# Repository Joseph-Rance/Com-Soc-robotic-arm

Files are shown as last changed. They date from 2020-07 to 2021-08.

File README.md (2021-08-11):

**WE'RE DONE! Thanks to everyone who took part! ([VIDEO](https://github.com/Joseph-Rance/Com-Soc-robotic-arm/blob/master/final%20video.mp4))**

# Com-Soc-robotic-arm
Repo for the code for our robotic arm project

Main Com Soc Repo: https://github.com/CRGS-Computing-Society/Com-Soc-main

## Object detection

The program first takes in an image like the one below as well as an image of the same scene but without objects on it.

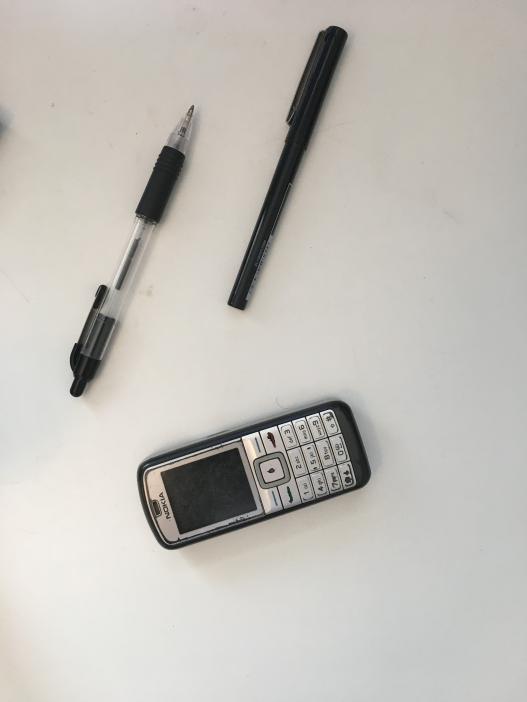
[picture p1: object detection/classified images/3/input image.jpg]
input image


It then takes the difference between the two images to get a map of where the added objects may be, cleans the map up, and then finds the centre of the objects using DBSCAN. Below shows the predicted centres of objects in the image, marked by red dots.

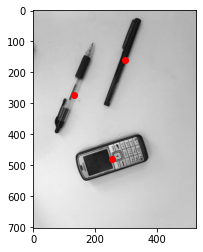
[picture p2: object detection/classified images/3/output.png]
output image


*Note: The only inputs are the background image and the image with objects in. No other information is used, including how many objects are in the image*

The algorithm also identifies the best angle to rotate the hand to get the best grip on the object

## Cad model render

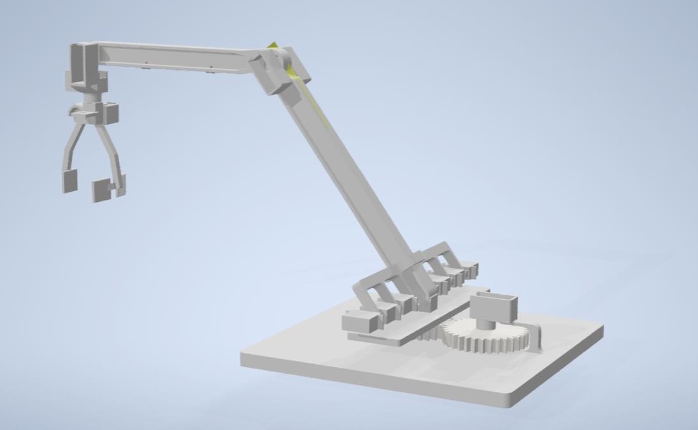
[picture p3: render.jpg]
arm render


# TODO

- [X] finish TODOs in [combined/main.py](https://github.com/Joseph-Rance/Com-Soc-robotic-arm/blob/master/combined/main.py)
- [x] fix issues with servo power supply (add new cables?)
- [X] test code with each set of servos ~~+ update code to reduce jitter and allow for gearing~~
- [X] add servos in at the correct orientation
- [X] test arm as whole + fix any problems (inc. fixing horizontal rotate servo, up/down gripper, and checking main.py is up to date with move_arm.py)

# servo offsets

```
0 -> 0 to 25
1 -> 90 (inv)
2 -> 0
3 -> 0
4 -> 0 (inv)
5 -> -3
6 -> -3
7 -> 0
8 -> 5 (inv)
9 -> 12 (inv)
10 -> 5 (inv)
11 -> 22 (inv, gear)
```

**Calibration dots are (-10, 35), (10, 30) cm**

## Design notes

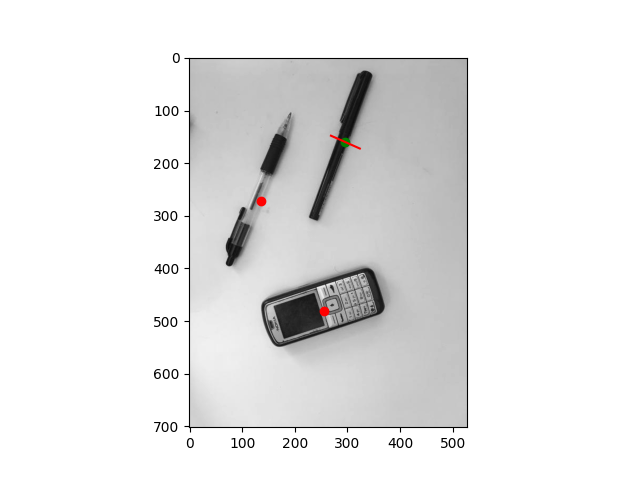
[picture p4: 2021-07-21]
object detection.png

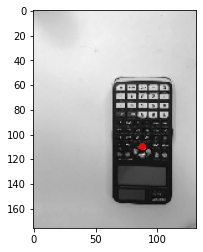
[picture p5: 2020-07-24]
object detection/classified images/2/output.png

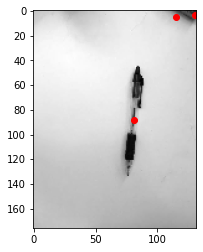
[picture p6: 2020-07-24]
object detection/classified images/1/output.png

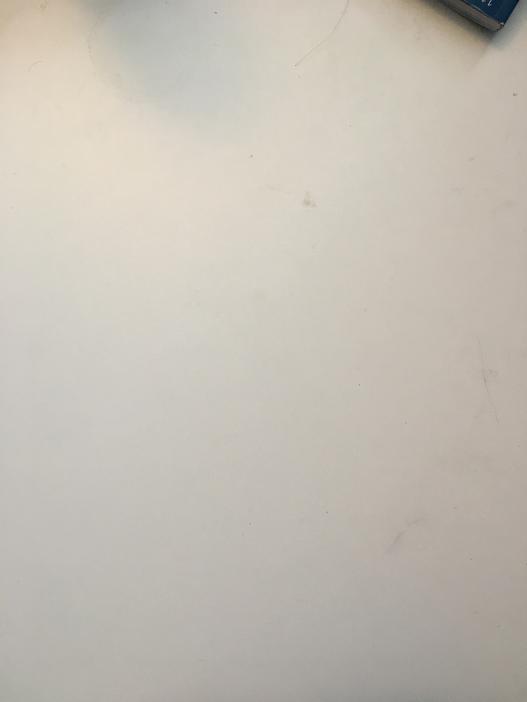
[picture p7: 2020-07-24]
object detection/classified images/1/input background.jpg

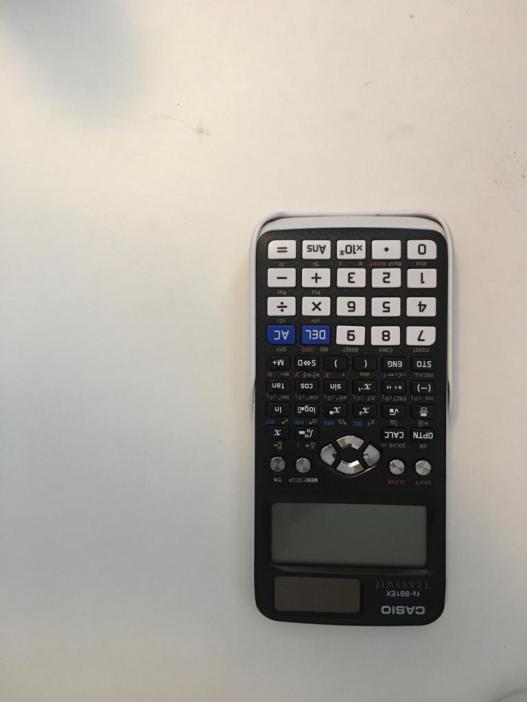
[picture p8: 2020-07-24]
object detection/classified images/2/input image.jpg

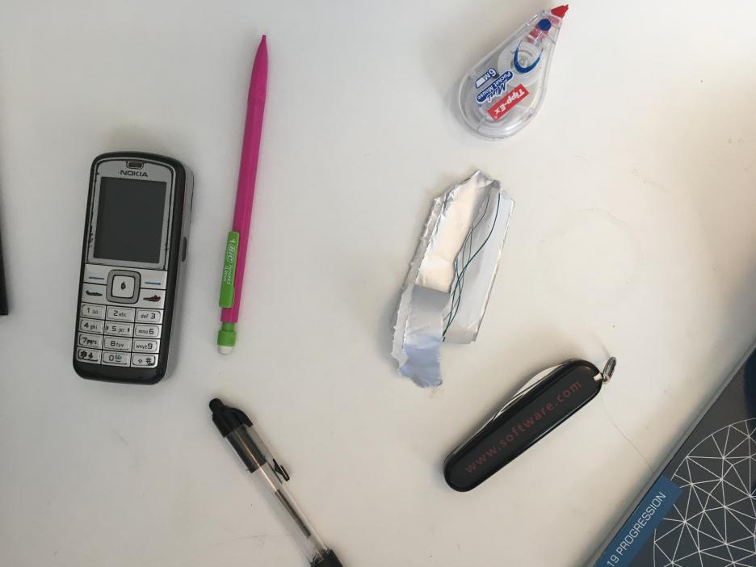
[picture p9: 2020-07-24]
object detection/classified images/4/input image.jpg

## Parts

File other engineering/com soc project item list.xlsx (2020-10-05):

Item | Link | Price (£)
Raspberry Pi | https://thepihut.com/products/raspberry-pi-4-model-b?variant=20064052740158 | 54
Pi camera display cable extension | https://www.adafruit.com/product/2143 | 3.95
GPIO extension cables | https://www.amazon.co.uk/AZDelivery-MB-102-Breadboard-Kit/dp/B07KYHBVR7 | 5.49
Cable ties | https://www.amazon.co.uk/100-Pack-Black-Cable-Ties/dp/B07BGTR4G4 | 5.69
Power supply (rpi) | https://thepihut.com/products/official-raspberry-pi-universal-power-supply?src=raspberrypi | 9
3D printer filament (2 for safety) | https://www.amazon.co.uk/ANYCUBIC-Printer-Filament-Printing-Printers/dp/B07DMF9ZRL | 61.96
Servos (6 * 2) | https://www.amazon.co.uk/Diymore-Digital-Helicopter-Airplane-controls/dp/B07DQJ1JXY | 53.8
Camera | https://thepihut.com/products/raspberry-pi-camera-module?src=raspberrypi | 24
Rubber pads for gripper | https://www.amazon.co.uk/Adhesive-Bumpers-Cylindrical-Hemispherical-Trapezoid/dp/B01M7OAWNU | 6.99
usb-c adapter | https://thepihut.com/products/usb-b-to-usb-c-adapter | 1
servo controller | https://www.adafruit.com/product/815 | 14.95
servo controller power supply | https://www.amazon.co.uk/Adapter-aifulo-Universal-Adapters-Speakers/dp/B08CZ9VTSH | 8.99
 |  | 249.82 | (max is £250)

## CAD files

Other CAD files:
cad/Spur Gear16.ipt
cad/Spur Gear26.ipt
cad/Spur Gears6.iam
cad/arm base holder 1.ipt
cad/arm.iam
cad/bullet bill 1.ipt
cad/cross section 2.ipt
cad/moving gripper 2.ipt
cad/servo holder 2.ipt
cad/servo placeholder.ipt
cad/stationary gripper 7.ipt
cad/wood part 1.ipt
cad/wood part 2.ipt
cad/wrist 3.ipt
cad/x arm 2.ipt
cad/y arm 2.ipt
cad/y arm connection.ipt

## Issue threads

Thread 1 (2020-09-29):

TODO

Joseph-Rance, 2020-09-29:
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

Joseph-Rance, 2020-10-16:
UPDATE 16/10/2020:

I got together a list of parts for the servo power supply, and the components have been sent off. We will be meeting at 6:30 Saturday to discuss the CAD modelling

BlueScorch2, 2020-10-20:
:]

Joseph-Rance, 2020-10-20:
From the call:
1. ~~What type of Claw to use~~ one finger will bee fixed, the other attached to servo. the stationary finger will be split in two (not too wide though)
2. ~~Best way to attach servos to arm- ie. 3d printed mould, glue, etc~~ Glue in bottom of cup
3. ~~Best way to attach servo axles to next part~~ see pinned diagram; see pinned link for servo connection
4. ~~What type of base (eg should we just stick it to a big piece of mdf)~~ make sheet on bottom go paast servos to put weight on (e.g. book)
5. ~~Best cross section shape~~ needs cad stress testing
6. ~~how to connect the arm to the servo axles~~ see pinned  diagram (3)
7. ~~how to connect the joints~~ see pinned  diagram (3)
8. ~~how to connect that arm together in general~~ see second pinned diagram
10. ~~modularity?~~ use modular fingers (make them easily removable
11. add camera mount to gripper
12. see last pinned diagram for servo locations

Joseph-Rance, 2020-10-20:
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
[link](https://www.amazon.co.uk/Diymore-Digital-Helicopter-Airplane-controls/dp/B07DQFXDC9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)
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

Joseph-Rance, 2020-10-23:
Because we need to make a decision on this and I keep forgetting to bring it up in meetings, I'm just going to make it now: x = 0.4m; y = 0.35m.

Joseph-Rance, 2020-10-23:
**MESSAGE FROM COM SOC DISCORD**
@BlueScorch2#0323 @Greedypig212#6943 @Rebi#9845 So its going to be us 4 and Hemanth working on the arm.

Mr. McCain mentionned that we have two different 3D printers when we met him at lunch. The filament we are getting is 1.75mm so we'll be using the *flash forge finder* (in case you need any specifications for part size etc.)

I think it will be best if we give each person a specific part to work on. I want to decide what everyone is going to be doing ASAP so if anyone is feeling inspired they can begin already, however we have admissions tests coming up so we'll only properly begin modelling on the week beginning the 9th. I think we should aim to have models complete two weeks after that.

Of course, we will almost certainly meet more problems and decisions, so if there are any issues I'm happy to do a meeting (or dm) to talk about them. Also, we'll have to collaborate a bit to decide how each part will connect to the others, so we need to all meet at some point anyways.

Info for modelling (inc. notes from last meeting) should be here: https://github.com/Joseph-Rance/Com-Soc-robotic-arm/issues/1

If you have a question, that above link may be a good place to ask it so everyone else can see.

With regards to who is doing what, does anyone have any preferences? Also how much each person is willing to do? I imagine we'll split the components up like below:
person 1: alpha hinge + servo holders for alpha
person 2: beta hinge + servo holders for beta
person 3: gamma hinge + servo holders for gamma
person 4: grabber + camera
person 5: x and y beam (+ wire management)

Also, is it possible to get a channel in the eng soc team so we can include Hemanth (and anyone who joins late) in all this?

Joseph-Rance, 2020-11-06:
Com Soc team todo:
 - [ ] Fix rotation finder
 - [ ] Begin servo control

Joseph-Rance, 2020-11-07:
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

Joseph-Rance, 2020-11-14:
![Uploading image.png…]()

Joseph-Rance, 2020-11-14:
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

Joseph-Rance, 2020-11-14:
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

Joseph-Rance, 2020-11-14:
40x19x43

Joseph-Rance, 2020-11-14:
Todo before 5pm saturday:
Akilan: Base rotation start
Gwon: Blue section start
Hemanth: Black section start

Joseph-Rance, 2020-11-20:
Another diagram similar to the ones above
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

Joseph-Rance, 2021-01-30:
Joe (by next week):
 - [ ] Add camera mount to gripper
 - [ ] make "wrist" section

Hemanth:
 - [ ] start the "elbow section"

Gwon:
 - [ ] start on base

Joseph-Rance, 2021-01-30:
[robot arm main.zip](https://github.com/Joseph-Rance/Com-Soc-robotic-arm/files/5898469/robot.arm.main.zip)

Joseph-Rance, 2021-01-31:
If anyone needs the servo layout the most up to date conversation I can find about that on discord has this layout:
1 servo for gripper finger movement
1 servo for gripper rotation
1 servo for gripper up/down
2 servos at "elbow"
6 servos at base for up/down
1 servo for base sideways rotation

Joseph-Rance, 2021-01-31:
new gripper and x section files: [robot arm main.zip](https://github.com/Joseph-Rance/Com-Soc-robotic-arm/files/5899838/robot.arm.main.zip)
badly edited image of them together:
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

Joseph-Rance, 2021-01-31:
Update: [robot arm main (2).zip](https://github.com/Joseph-Rance/Com-Soc-robotic-arm/files/5899904/robot.arm.main.2.zip)
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

GwonWorks, 2021-02-06:
[BaseGears1.zip](https://github.com/Joseph-Rance/Com-Soc-robotic-arm/files/5937386/BaseGears1.zip)

Joseph-Rance, 2021-02-06:
[robot arm main.zip](https://github.com/Joseph-Rance/Com-Soc-robotic-arm/files/5937425/robot.arm.main.zip)

Joseph-Rance, 2021-02-07:
> Update: [robot arm main (2).zip](https://github.com/Joseph-Rance/Com-Soc-robotic-arm/files/5899904/robot.arm.main.2.zip)
> 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

I just realised that the rightmost servo here needs to be facing the left

Joseph-Rance, 2021-02-07:
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
[robot arm main (2).zip](https://github.com/Joseph-Rance/Com-Soc-robotic-arm/files/5939990/robot.arm.main.2.zip)

GwonWorks, 2021-02-14:
[BaseGears2.zip](https://github.com/Joseph-Rance/Com-Soc-robotic-arm/files/5978162/BaseGears2.zip)
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

GwonWorks, 2021-02-14:
Does this update live?

Joseph-Rance, 2021-02-14:
- [ ] Joe: Make y part of the elbow
 - [ ] Hemanth: Make x part of the elbow:
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
inner circle diameter is 25mm
distance between servos is 25mm
 - [ ] Gwon: Make bit for x arm to rest on (+ remove connection to base of servo)
 - [ ] Akilan:
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

Akilan and Hemanth: make your x section end in I shape

Files:
[robot arm main (3).zip](https://github.com/Joseph-Rance/Com-Soc-robotic-arm/files/5978217/robot.arm.main.3.zip)

Joseph-Rance, 2021-02-14:
left to do:
 - make connections to servos

Joseph-Rance, 2021-02-15:
changes to beta/elbow/xy joint:
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
[updated models.zip](https://github.com/Joseph-Rance/Com-Soc-robotic-arm/files/5983556/updated.models.zip)

BlueScorch2, 2021-02-15:
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
[bullet bill.zip](https://github.com/Joseph-Rance/Com-Soc-robotic-arm/files/5983988/bullet.bill.zip)
(>'-')>

GwonWorks, 2021-02-21:
[BaseArmHolder.zip](https://github.com/Joseph-Rance/Com-Soc-robotic-arm/files/6018130/BaseArmHolder.zip)
![Uploading image.png…]()

Joseph-Rance, 2021-02-21:
[cad.zip](https://github.com/Joseph-Rance/Com-Soc-robotic-arm/files/6018229/cad.zip)
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

Joseph-Rance, 2021-02-22:
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

Joseph-Rance, 2021-06-08:
5.85 mm diameter spline

Joseph-Rance, 2021-06-08:
![Uploading image.png…]()

Joseph-Rance, 2021-06-09:
https://www.amazon.co.uk/gp/product/B07FY2T89M/

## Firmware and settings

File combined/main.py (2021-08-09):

import numpy as np
from sys import argv
import time
from math import atan, atan2, pi, asin, acos, cos, sin, radians, degrees
import matplotlib.pyplot as plt
from matplotlib.image import imread
from adafruit_servokit import ServoKit
from picamera import PiCamera as p

def median_filter(input_image, s):
    new_image = np.zeros((input_image.shape[0], input_image.shape[1]))
    for r in range(0, input_image.shape[1]):
        for c in range(0, input_image.shape[0]):
            values = []
            for ri in range(max(0, r - s), min(input_image.shape[1], r + s)):
                for ci in range(max(0, c - s), min(input_image.shape[0], c + s)):
                    values.append(input_image[ci, ri])
            values = sorted(values)
            new_image[c, r] = values[int(len(values) / 2)]

    return new_image


downsize = lambda img, sf: np.array(
    [[img[j, i] for i in range(0, len(img[0]), sf)] for j in range(0, len(img), sf)])
threshold_function = lambda image, threshold: np.asarray(
    [[pixel >= threshold for pixel in row] for row in image])

def dilate(image, radius):
    new_image = np.zeros(image.shape)
    image = np.pad(image, radius, "constant")
    for y in range(new_image.shape[0]):
        for x in range(new_image.shape[1]):
            coords = [[(y+j+radius, x+i+radius) for j in range(-radius, radius+1)] for i in range(-radius, radius+1)]
            total = np.asarray([[image[j] for j in i] for i in coords]).any()
            new_image[y, x] = total != 0
    return new_image

def DBSCAN(image, radius, core_threshold):

    points = []

    for y in range(len(image)):
        for x in range(len(image[y])):
            if image[y, x] == 1:
                points.append([(y, x), 0])

    groups = [0]  # group 0 -> noise (default)

    for point in points:

        surrounding_points = []
        for other_point in points:
            if ((point[0][0] - other_point[0][0])**2 + (point[0][1] - other_point[0][1])**2)**0.5 <= radius and point != other_point:
                surrounding_points.append(other_point)

        if len(surrounding_points) >= core_threshold:

            if sum([p[1] for p in surrounding_points]) == 0:  # no groups
                new_group = groups[-1] + 1
                groups.append(new_group)

                for p in surrounding_points:
                    p[1] = new_group  # changes main points list as list is reference

            elif sum([p[1] > 0 for p in surrounding_points]) == 1:  # one group

                group = -1  # group should never stay -1
                for p in surrounding_points:
                    group = p[1] if p[1] > 0 else group

                for p in surrounding_points:
                    p[1] = group

            else:  # >1 group

                surrounding_groups = []
                for p in surrounding_points:
                    if p[1] not in surrounding_groups and p[1] != 0:
                        surrounding_groups.append(p[1])

                for p in surrounding_points:
                    p[1] = surrounding_groups[0]

                for p in points:
                    if p[1] in surrounding_groups:
                        p[1] = surrounding_groups[0]

    del groups[0]  # noise group
    centres = [[0, 0] for i in groups]
    totals = [0 for i in groups]

    for point in points:
        if point[1] != 0:
            centres[groups.index(point[1])][0] += point[0][0]
            centres[groups.index(point[1])][1] += point[0][1]
            totals[groups.index(point[1])] += 1

    for i in range(len(groups)):
        if totals[i] > 0:
            centres[i][0] /= totals[i]
            centres[i][1] /= totals[i]

    loss = 0
    for point in points:
        distances = np.array([((point[0][0] - centre[0])**2 + (point[0][1] - centre[1])**2)**0.5 for centre in centres])
        loss += min(distances)

    del_list = []
    for i in range(len(centres)):
        if centres[i] == [0, 0]:
            del_list.append(i)
    for i in sorted(del_list)[::-1]: del centres[i]

    return points, centres, loss

def get_gripper_angle(image, centres, centre_idx=0, debug=False):

    def check_line_length(centre, angle, image):  # angle is from line to right

        def dist(p1, p2):
            return ((p1[0] - p2[0])**2 + (p1[1] - p2[1])**2)**0.5

        hyp = 0
        still_on_obj_pos = still_on_obj_neg = True
        coords = [(), ()]

        while still_on_obj_pos or still_on_obj_neg:
            hyp += 2
            dy = hyp * sin(angle)  # keep angle in radians
            dx = hyp * cos(angle)
            try:
                if image[round(centre[0]+dy), round(centre[1]+dx)] == 0 and still_on_obj_pos:
                    still_on_obj_pos = False
                    coords[0] = (round(centre[0]+dy), round(centre[1]+dx))
            except IndexError:
                if still_on_obj_pos:
                    still_on_obj_pos = False
                coords[0] = (round(centre[0]+dy), round(centre[1]+dx))

            try:
                if image[round(centre[0]-dy), round(centre[1]-dx)] == 0 and still_on_obj_neg:
                    still_on_obj_neg = False
                    coords[1] = (round(centre[0]-dy), round(centre[1]-dx))
            except IndexError:
                if still_on_obj_neg:
                    still_on_obj_neg = False
                    coords[1] = (round(centre[0]-dy), round(centre[1]-dx))

        return dist(*coords)

    if debug:
        return [check_line_length(centres[centre_idx], radians(angle), image) for angle in range(0, 180, 2)]
    return 2*np.argmin(np.asarray([check_line_length(centres[centre_idx], radians(angle), image) for angle in range(0, 180, 2)]))  # only one returned because we only do one rotation per time

def move_centres(image, centres):

    new_centres = [(1e5, 1e5) for i in centres]

    def dist(p1, p2):
        return ((p1[0] - p2[0])**2 + (p1[1] - p2[1])**2)**0.5

    points = []

    for y in range(len(image)):
        for x in range(len(image[y])):
            if image[y,x] == 1:
                points.append((y,x))

    for point in points:
        for i, centre in enumerate(centres):
            distance = dist(point, centre)
            if distance < new_centres[i][1]:
                new_centres[i] = (point, distance)

    return [i[0] for i in new_centres]

def detect_objs(img1, img2, parameters):

    img = np.absolute(img1 - img2)
    img = downsize(img, parameters["scaling"])
    img = median_filter(img, parameters["filter_radius"])
    img = threshold_function(img, parameters["threshold"])
    centres = DBSCAN(img, parameters["dbscan_radius"], parameters["dbscan_core_threshold"])[1]
    centres = move_centres(img, centres)
    img = dilate(img, parameters["dilate_size"])
    try:
        angle = get_gripper_angle(img, centres, int(parameters["centre_idx"]))
    except IndexError:
        raise RuntimeError("objects not found")

    return centres, angle, img

class servo_control(object):

    offsets, scalings = (0, 0), (1, 1)  # (x,y)

    def __init__(self, drop_pos):
        if input("Calibrate arm? (y/n) ") == "y":
            self.calibrate()
        self.drop_pos = drop_pos

    def calibrate(self):

        def get_calibration_image():
            img = imread('calibration image.jpg')
            if img.ndim == 3:
                img = img.mean(axis=2)
            return img

        image = get_calibration_image()

        a, b, c, d = input("what are the real positions in m of the dots in the image? (in format: 'x, y, x, y') ").split(", ")
        real_1, real_2 = (float(a), float(b)), (float(c), float(d))

        exit = False
        while not exit:
            a, b, c, d = input("What are the positions in pixels of the dots in the image? (in format: 'x, y, x, y') ").split(", ")
            image_1, image_2 = (float(a), len(image)-float(b)), (float(c), len(image)-float(d))

            plt.imshow(image)
            plt.scatter([int(a), int(c)], [int(b), int(d)])
            plt.savefig("image.jpg")

            exit = input("Would you like to change these values? (y/n) ") != "y"

        plt.imshow(image)
        plt.scatter([int(a), int(c)], [int(b), int(d)])
        plt.savefig("image.jpg")
        
        '''        
        x_i*s_x + o_x = x_r
        image_1[0] * self.scalings[0] + self.offsets[0] = real_1[0]
        image_2[0] * self.scalings[0] + self.offsets[0] = real_2[0]
        
        y_i*s_y + o_y = y_r
        image_1[1] * self.scalings[1] + self.offsets[1] = real_1[1]
        image_2[1] * self.scalings[1] + self.offsets[1] = real_2[1]
        
        so:
        image_1[0] * self.scalings[0] + self.offsets[0] - image_2[0] * self.scalings[0] - self.offsets[0] = real_1[0] - real_2[0]
        image_1[0] * self.scalings[0] - image_2[0] * self.scalings[0] = real_1[0] - real_2[0]
        self.scalings[0] = (real_1[0] - real_2[0]) / (image_1[0] - image_2[0])
        so long as image_1[0] != image_2[0]
        
        and self.offsets[0] = real_2[0] - image_2[0] * self.scalings[0]
        
        similarly:
        self.scalings[1] = (real_1[1] - real_2[1]) / (image_1[1] - image_2[1])
        self.offsets[1] = real_2[1] - image_2[1] * self.scalings[1]
        
        '''
    
        try:
            scaling_x = (real_1[0] - real_2[0]) / (image_1[0] - image_2[0])
            scaling_y = (real_1[1] - real_2[1]) / (image_1[1] - image_2[1])
        except:
            raise ValueError("division by zero due to points being aligned in x or y. Try again with different image x,y values")

        scalings = (scaling_x, scaling_y)

        offset_x_1 = real_1[0] - image_1[0] * scalings[0]
        offset_x_2 = real_2[0] - image_2[0] * scalings[0]
        #assert offset_x_1 == offset_x_2

        offset_y_1 = real_1[1] - image_1[1] * scalings[1]
        offset_y_2 = real_2[1] - image_2[1] * scalings[1]
        #assert offset_y_1 == offset_y_2

        offsets = (offset_x_1, offset_y_1)
    
        self.scalings, self.offsets = scalings, offsets

        return offsets, scalings

    def get_rotations(self, x_coord, y_coord, z_coord, w, c, x=40, y=35, a=7, open_ang=radians(0), close_ang=radians(25)):

        '''
        theta:    angle at the base for horizontal rotation (clockwise from the vertical)
        alpha:    angle at the base for vertical roation
        beta:     angle at the elbow for vertical
        gamma:    angle at the wrist for vertical
        w:        wrist rotation
        r:        radius    
        z_coord:  height of hand
        c:        open(0)/closed(1)
        o:        rotation for finger
        a:        length of wrist
        x_coord:  x coord
        y_coord:  y coord
        x:        x arm length 
        y:        y arm length
        '''

        if c:
            o = close_ang
        else:
            o = open_ang

        r = (x_coord**2 + y_coord**2)**0.5
        theta = pi/2 - atan2(y_coord, x_coord)

        b = r**2 + (a+z_coord)**2
        alpha = pi - asin((x**2 - y**2 + b)/(2*x*(b**0.5))) - atan((r)/(a+z_coord))
        beta = acos((x*cos(alpha)-(r))/y) - alpha

        gamma = 3*pi/2 - alpha - beta

        return theta, alpha, beta, gamma, w, o

    def get_route(self, w, x, y, z=20, x_len=40, y_len=40, a_len=0.07, open_ang=10, close_ang=30):  # x,y in pixels

        if z < 0.01:
            raise ValueError("DONT HIT THE TABLE")

        x = self.offsets[0] + self.scalings[0]*x
        y = self.offsets[1] + self.scalings[1]*y
        
        print(f"picking up object at (x, y, z)={(x, y, z)}")

        h = 0.05  # height above object
                
        args = (x_len, y_len, a_len, open_ang, close_ang)
        
        #print([
        #    (x, y, z+h, w, 0, *args),  # go above object
        #    (x, y, z, w, 0, *args),  # go down to object
        #    (x, y, z, w, 1, *args),  # grab object
        #    (x, y, z+h, w, 1, *args),  # go up from table
        #    (self.drop_pos[0], self.drop_pos[1], z+h, 0, 1, *args),  # go to drop position
        #    (self.drop_pos[0], self.drop_pos[1], z+h, 0, 0, *args)  # drop object
        #])

        actions = [
            self.get_rotations(x, y, z+h, w, 0, *args),  # go above object
            self.get_rotations(x, y, z, w, 0, *args),  # go down to object
            self.get_rotations(x, y, z, w, 1, *args),  # grab object
            self.get_rotations(x, y, z+h, w, 1, *args),  # go up from table
            self.get_rotations(self.drop_pos[0], self.drop_pos[1], z+h, 0, 1, *args),  # go to drop position
            self.get_rotations(self.drop_pos[0], self.drop_pos[1], z+h, 0, 0, *args)  # drop object
        ]

        return actions

def get_params(args):

    parameters = {"scaling": 32,
                  "filter_radius": 2,
                  "threshold": 30,
                  "dbscan_radius": 4,
                  "dbscan_core_threshold": 10,
                  "dilate_size": 2,
                  "centre_idx": 0,
                  "photo_location_x": 0,
                  "photo_location_y": 30,
                  "photo_location_z": 35,
                  "pickup_height": 0.1,
                  "x_arm_length": 40,
                  "y_arm_length": 35,
                  "a_arm_length": 16,
                  "drop_location_x": -20,
                  "drop_location_y": 20,
                  "drop_location_z": 20,
                  "grabber_open_angle": 0,
                  "grabber_close_angle": 25}

    exit = False
    try:
        if args[0] == "help":
            print(f"default params: {parameters}")
            exit = True
    except:
        pass

    if exit:
        quit()

    for arg in args:
        arg = arg.split("=")
        assert len(arg) == 2

        if arg[0] not in parameters:
            raise ValueError(f"{arg[0]} is not an accepted parameter!")

        parameters[arg[0]] = float(arg[1])

    return parameters

def move_servos(route, servos, speed=1):

    route = [[degrees(i) for i in j] for j in route]
    
    '''
    servos:
    0 -> gripper
    1 -> gripper sideways rotate
    2 -> gripper up/down rotate
    3, 4 -> y arm up/down
    5,6,7,8,9,10 -> x arm up/down
    11 -> horiz. rotcentresate
    '''
    for (theta, alpha, beta, gamma, w, o) in route:
        
        '''
        theta:    angle at the base for horizontal rotation (clockwise from the vertical)
        alpha:    angle at the base for vertical roation
        beta:     angle at the elbow for vertical
        gamma:    angle at the wrist for vertical
        w:        wrist rotation
        o:        rotation for finger
        '''
        
        servos[0].angle = radians(o)  # why is this necessary???
        try:
            servos[1].angle = 90 - w
        except ValueError:
            pass  # this is not vital for functioning and idk whats wrong
        servos[2].angle = 180 - gamma
        servos[3].angle = beta
        servos[4].angle = 145 - beta

        servos[5].angle = servos[6].angle = 145 - alpha - 3  # 145 is max rotation
        servos[7].angle = 145 - alpha
        servos[8].angle = servos[10].angle = alpha + 5
        servos[9].angle = alpha + 12

        servos[11].angle = theta * -0.75 + 27

        time.sleep(1)  # ensure servos have finished moving before next move

def main():

    args = argv[1:]  # python main.py scaling=0.1
    parameters = get_params(args)

    camera = p()
    camera.rotation = 90  # TODO: make sure this is correct so that "down" is towards base of arm
    camera.capture("/home/pi/Desktop/calibration image.jpg")

    controller = servo_control((parameters["drop_location_x"], parameters["drop_location_y"], parameters["drop_location_z"]))
    kit = ServoKit(channels=16)
    servos = kit.servo
    
    for i in range(16):
            servos[i].actuation_range = 145

    camera.capture("/home/pi/Desktop/input background.jpg")
    img1 = imread('input background.jpg')
    if img1.ndim == 3:
        img1 = img1.mean(axis=2)

    input("background image taken (press enter to continue...)")
    
    no_objects = 1
    while no_objects != 0:

        print("taking images")

        rotations = controller.get_rotations(parameters["photo_location_x"],  # move to position to take images
                                             parameters["photo_location_y"],
                                             parameters["photo_location_z"],
                                             0, 0,
                                             parameters["x_arm_length"],
                                             parameters["y_arm_length"],
                                             parameters["a_arm_length"],
                                             radians(parameters["grabber_open_angle"]),
                                             radians(parameters["grabber_close_angle"]))

        move_servos([rotations], servos)
        
        for i in range(12):  # reduce jitter when stationary
            servos[i].angle = None

        camera.capture("/home/pi/Desktop/input image.jpg")
        img2 = imread('input image.jpg')
        if img2.ndim == 3:
            img2 = img2.mean(axis=2)

        print("searching for objects")

        start_time = time.perf_counter()
        centres, angle, img = detect_objs(img1, img2, parameters)
        print(f"Detection time: {round(time.perf_counter() - start_time, 2)}s")

        
        plt.imshow(img2, cmap="gray")
        plt.plot([centres[parameters["centre_idx"]][1]*parameters["scaling"]-30*cos(radians(angle)),
                centres[parameters["centre_idx"]][1]*parameters["scaling"]+30*cos(radians(angle))],
                [centres[parameters["centre_idx"]][0]*parameters["scaling"]-30*sin(radians(angle)),
                centres[parameters["centre_idx"]][0]*parameters["scaling"]+30*sin(radians(angle))], c="r")
        for i in range(len(centres)):
            plt.scatter(centres[i][1]*parameters["scaling"], centres[i][0]*parameters["scaling"], c="g" if i == parameters["centre_idx"] else "r")
        plt.savefig("detected objects.jpg")      

        image_height = len(img1)
        centres = [(x*parameters["scaling"], y*parameters["scaling"]) for x,y in centres]
        centres = [(image_height-y, x) for y, x in centres]

        angle = radians(angle)
        angle -= pi/2  # convert angle to be zeroed for arm
        while angle < -pi/2:
            angle += pi
            
        print(angle)

        no_objects = len(centres)
        if no_objects == 0:
            break

        print("getting rotations for arm")

        route = controller.get_route(angle,
                                     centres[int(parameters["centre_idx"])][1],
                                     centres[int(parameters["centre_idx"])][0],
                                     parameters["pickup_height"],
                                     parameters["x_arm_length"],
                                     parameters["y_arm_length"],
                                     parameters["a_arm_length"],
                                     parameters["grabber_open_angle"],
                                     parameters["grabber_close_angle"])

        print("arm moving")
        
        print(route)

        move_servos(route, servos)
        
        for i in range(12):  # reduce jitter when stationary
            servos[i].angle = None

    camera.close()
    print("Done.")

if __name__ == "__main__":
    main()

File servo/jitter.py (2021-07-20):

from adafruit_servokit import ServoKit
from time import sleep

kit = ServoKit(channels=16)

for i in range(12):
    kit.servo[i].actuation_range = 145

while True:
    kit.servo[0].angle = 0
    sleep(0.2)
    kit.servo[0].angle = None
    sleep(2)

    kit.servo[0].angle = 10
    sleep(0.2)
    kit.servo[0].angle = None
    sleep(2)

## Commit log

2021-02-16 Add files via upload
    Joint at base of the arm :]
2021-02-22 add final models
    [Spur Gear16.ipt, Spur Gear26.ipt, arm base holder 1.ipt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]
2021-05-19 fixed dilate function so that it works with different radii
    [main.py]
2021-05-19 fix an issue with code that doesnt make any sense
    [main.py]
2021-05-19 fix code that was already fixed
    [main.py]
2021-07-21 reorganised files
    [Spur Gear16.ipt, Spur Gear26.ipt, Spur Gears6.iam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]
2021-07-26 turn servos off when stationary to reduce jitter
    [main.py]
2021-07-27 make base rotate in correct direction
    [main.py]
2021-08-04 add camera rotation
